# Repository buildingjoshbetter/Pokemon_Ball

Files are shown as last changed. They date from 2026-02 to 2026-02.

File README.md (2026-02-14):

<p align="center">
  PokeBall OpenClaw
</p>

<h1 align="center">PokeBall OpenClaw</h1>

<p align="center">
  <strong>Your AI agent, captured.</strong><br>
  A living PokeBall that thinks, glows, and talks back.
</p>

<p align="center">
  <a href="#installation">Install</a> · <a href="#what-it-does">What It Does</a> · <a href="#why">Why</a> · <a href="#demo">Demo</a>
</p>

---

## What It Does

PokeBall OpenClaw is a 3D-printed PokeBall with a Raspberry Pi 5 inside, running [OpenClaw](https://openclaw.ai) — the open-source AI agent. You talk to it through Telegram. It thinks using Claude, GPT, or whatever LLM you point it at. And while it works, the center button glows to tell you what's happening.

Blue means it's thinking. Green means it answered. Red means something broke. When nobody's talking to it, it breathes — a slow green pulse, like it's sleeping inside the ball, waiting.

It's not a toy. It's a fully functional AI assistant that happens to live inside the most iconic capture device in fiction.

### Features

- **LED state engine** — A stack-aware state machine drives three LEDs through the PokeBall's translucent button. Seven distinct states: boot, idle, thinking, tool call, success, error, disconnected. The transitions are instantaneous — you see the ball react the moment you hit send.
- **Heartbeat watchdog** — The OpenClaw plugin pings the LED daemon every 5 seconds. If the gateway crashes, the ball knows. Slow red pulse. No false positives, no polling logs, no fragile workarounds.
- **Fire-and-forget architecture** — The LED system never interferes with the agent. Every call from the plugin to the daemon is wrapped in try/catch. If the LEDs die, the agent keeps working. Nice-to-have, not a dependency.
- **Telegram-native** — Designed for Telegram via OpenClaw's built-in channel. Message the bot, watch the ball, get your answer. No app, no dashboard, no browser tab.
- **Fully reproducible** — Five STL files, three LEDs, three resistors, one Pi. Every file you need is in this repo. Print it, wire it, run one script, you're live.
- **Always on** — systemd service starts the LED daemon on boot. Power cycle the Pi and everything comes back automatically. Hackathon-grade reliability.

## Installation

### Prerequisites

- [OpenClaw](https://github.com/openclaw/openclaw) installed and configured
- Telegram bot set up in OpenClaw (create one via [@BotFather](https://t.me/BotFather))
- Raspberry Pi 5 (8GB recommended) or Pi 4 (4GB minimum)
- 3D-printed PokeBall shell ([STL files included](stl/))

### Quick Install

1. Clone this repo onto your Pi:
```bash
git clone https://github.com/buildingjoshbetter/Pokemon_Ball.git
cd Pokemon_Ball
```

2. Run the setup script:
```bash
chmod +x scripts/setup-pi.sh
./scripts/setup-pi.sh
```

3. Add your Telegram bot token to `~/.openclaw/openclaw.json`:
```json5
{
  channels: {
    telegram: {
      enabled: true,
      botToken: "YOUR_BOT_TOKEN_HERE"
    }
  },
  plugins: {
    "pokeball-led": {
      enabled: true
    }
  }
}
```

4. Restart OpenClaw:
```bash
openclaw gateway restart
```

5. Message your bot on Telegram. Watch the ball glow. That's it.

### Hardware Setup

Three LEDs, three resistors, one ground wire:

```
GPIO 17 (Pin 11) ──► 330Ω ──► Blue LED  ──► GND (Pin 9)
GPIO 27 (Pin 13) ──► 330Ω ──► Green LED ──► GND (Pin 9)
GPIO 22 (Pin 15) ──► 330Ω ──► Red LED   ──► GND (Pin 9)
```

Position all three behind the center button. The translucent plastic acts as a diffuser.

Full guides: [Wiring](hardware/wiring-guide.md) · [Assembly](hardware/assembly-guide.md) · [Parts List](hardware/parts-list.md) · [3D Printing](stl/README.md)

## Demo

Send a message. Watch the ball.

```
You: What's the weather in Austin today?

[PokeBall: 🟢 green pulse → 🔵 solid blue]

Agent: Currently 72°F and sunny in Austin, TX. High of 78°F expected
       this afternoon with clear skies through the evening.

[PokeBall: 🔵 blue → 🟢 green flash → 🟢 green pulse]
```

Ask something that requires tools — the ball blinks faster:

```
You: Search the web for the latest OpenClaw release notes

[PokeBall: 🟢 → 🔵 solid blue → 🔵 fast blink (tool call)]

Agent: OpenClaw 2026.2.12 was released today with patches for 40+
       security vulnerabilities. Key changes include...

[PokeBall: 🔵 fast blink → 🔵 solid → 🟢 flash → 🟢 pulse]
```

If something goes wrong, you know immediately:

```
You: Connect to my database and run the migration

[PokeBall: 🟢 → 🔵 solid → 🔴 fast blink]

Agent: Connection refused on port 5432. Is PostgreSQL running?

[PokeBall: 🔴 blink for 3s → 🟢 pulse]
```

Kill the OpenClaw gateway and the ball tells you:

```
$ openclaw gateway stop

[PokeBall: ... 15 seconds pass ... 🔴 slow pulse (breathing)]
[The ball knows. It's waiting for its trainer to come back.]

$ openclaw gateway start

[PokeBall: 🔴 slow pulse → 🟢 pulse]
[Back online. Ready.]
```

Run the full demo without Telegram:

```bash
bash scripts/demo-sequence.sh
```

## Why

I was sitting at a hackathon staring at a terminal. Everyone around me had the same thing — a laptop, a code editor, an agent running in a window somewhere. You couldn't tell who was running what. You couldn't tell if anything was happening. The AI was invisible.

And I thought: that's the problem with agents. Not just at hackathons — everywhere. You fire off a request and then you sit there. Is it thinking? Did it crash? Is it stuck in a loop? You check the terminal. You check the logs. You wait. The most powerful technology we've ever built, and it has the presence of a loading spinner.

I had a 3D printer. I had a Raspberry Pi. I had a PokeBall model I'd been meaning to print for two years. And I had OpenClaw, an open-source agent that runs on a Pi and talks through Telegram.

So I caught one.

Three LEDs behind the button. A Python daemon listening on localhost. An OpenClaw plugin that fires on every lifecycle event. When the agent thinks, the ball glows blue. When it finishes, green flash. When it fails, red. When nobody's talking to it, it breathes — slow green pulse, like something alive is sleeping inside.

The moment I put it on the table, people walked over. Not because the code was impressive — it's straightforward. They walked over because they could *see* the AI. For the first time, the invisible thing had a body. It sat on the desk and it glowed and it breathed and when you talked to it, it reacted. That changes how you think about it. That changes how everyone around you thinks about it.

$105 in parts. An afternoon of work. Every file you need is in this repo.

Your move.

## Built By

**[@Building_Josh](https://x.com/Building_Josh)**

Built at a hackathon because AI agents deserve a body, and every trainer deserves a PokeBall on their desk.

## License

[MIT](LICENSE) — Gotta catch 'em all. Or at least this one.

---

<p align="center">
  <em>"I caught an AI."</em>
</p>

<p align="center">
  PokeBall OpenClaw
</p>

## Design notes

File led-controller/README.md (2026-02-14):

# LED Controller

Python daemon that drives the PokeBall's LEDs based on state commands from the OpenClaw plugin.

## How It Works

The LED controller is a FastAPI server running on `127.0.0.1:8420`. It receives HTTP requests from the OpenClaw plugin and translates them into GPIO signals that control three LEDs (red, green, blue).

### API Endpoints

| Method | Endpoint | Description |
|---|---|---|
| `PUT` | `/state` | Set LED state (`{"state": "idle"}`) |
| `POST` | `/heartbeat` | Heartbeat from OpenClaw plugin |
| `GET` | `/status` | Get current LED state |

### State Machine

The controller uses a stack-aware state machine:

```
BOOT ──────► IDLE ◄──── SUCCESS
               │            ▲
               ▼            │
         AGENT_ACTIVE ──────┘
               │
               ▼
           TOOL_CALL ───► AGENT_ACTIVE (pop stack)

  Any state ──► ERROR
  Any state ──► DISCONNECTED (heartbeat timeout)
```

## Installation

### On the Raspberry Pi

```bash
chmod +x install.sh
./install.sh
```

This installs the daemon to `/opt/pokeball-openclaw/led-controller/`, creates a Python virtual environment, and sets up a systemd service that starts on boot.

### Manual Test

```bash
# Test LED wiring
python3 test_leds.py

# Test the daemon
uvicorn led_daemon:app --host 127.0.0.1 --port 8420

# In another terminal:
curl -X PUT http://127.0.0.1:8420/state \
  -H "Content-Type: application/json" \
  -d '{"state": "agent_active"}'
```

## Files

| File | Description |
|---|---|
| `led_daemon.py` | FastAPI server + heartbeat watchdog |
| `led_states.py` | State machine with stack-aware transitions |
| `led_hardware.py` | gpiozero GPIO abstraction |
| `test_leds.py` | Quick wiring verification script |
| `pokeball-leds.service` | systemd unit file |
| `install.sh` | Automated installer |

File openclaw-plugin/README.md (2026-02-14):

# OpenClaw PokeBall LED Plugin

OpenClaw plugin that bridges agent lifecycle events to the PokeBall's LED indicators.

## How It Works

This plugin hooks into four OpenClaw lifecycle events:

| Event | LED State | Visual |
|---|---|---|
| `before_agent_start` | Agent Active | Solid blue |
| `before_tool_call` | Tool Call | Fast blue blink |
| `after_tool_call` | Agent Active | Back to solid blue |
| `agent_end` (success) | Success | Green flash |
| `agent_end` (error) | Error | Red blink |

It also runs a background heartbeat service that pings the LED daemon every 5 seconds. If the daemon stops receiving heartbeats (gateway crash), it transitions LEDs to a disconnected state (slow red pulse).

## Installation

### 1. Build the plugin

```bash
cd openclaw-plugin
npm install
npm run build
```

### 2. Copy to OpenClaw plugins directory

```bash
cp -r dist/ ~/.openclaw/plugins/pokeball-led/
cp package.json ~/.openclaw/plugins/pokeball-led/
```

### 3. Enable in OpenClaw config

Add to `~/.openclaw/openclaw.json`:

```json5
{
  plugins: {
    "pokeball-led": {
      enabled: true
    }
  }
}
```

### 4. Restart OpenClaw gateway

```bash
openclaw gateway restart
```

## Configuration

Set the `POKEBALL_LED_URL` environment variable to override the default LED daemon URL:

```bash
export POKEBALL_LED_URL="http://127.0.0.1:8420"
```

## Files

| File | Description |
|---|---|
| `src/index.ts` | Plugin entry: registers hooks + heartbeat service |
| `src/led-client.ts` | HTTP client for the LED daemon |
| `src/hooks/agent-lifecycle/` | Agent start/end hook |
| `src/hooks/tool-lifecycle/` | Tool call start/end hook |

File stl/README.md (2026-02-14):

# 3D Printing Guide

Five parts make up the PokeBall enclosure. Print them separately with the colors and settings below.

## Parts Overview

| Part | File | Color | Description |
|---|---|---|---|
| Top Half | `top-half.stl` | **Red** | Upper shell of the PokeBall |
| Bottom Half | `bottom-half.stl` | **White** | Lower shell of the PokeBall |
| Center Band | `center-band.stl` | **Black** | Equator band that joins the two halves |
| Button | `button.stl` | **White or translucent** | Center button (LED shines through this) |
| Button Bezel | `button-bezel.stl` | **Dark gray or black** | Ring around the center button |

## Print Settings

| Setting | Value | Notes |
|---|---|---|
| Layer Height | 0.2mm | Standard quality, good enough for the shell |
| Infill | 15% | 20% for center band (structural) |
| Supports | Yes | For top-half and bottom-half interior cavities |
| Walls | 3 perimeters | Strength without excess weight |
| Material | PLA | PETG also works, PLA is easiest |
| Nozzle | 0.4mm | Standard |

## Special Notes

- **Button**: If you can print in translucent/clear PLA, do it. The LED behind it will glow through beautifully. If not, white PLA works fine - the light still diffuses through at 100% infill.
- **Top Half**: The interior needs supports. Orient it with the dome facing up.
- **Bottom Half**: Orient dome facing down. You may want to drill a small hole in the back for USB-C power cable access.
- **Center Band**: No supports needed. This is the structural piece - use 20% infill.
- **Button Bezel**: Small part, prints fast. Press-fits around the button.

## Assembly Order

1. Print all five parts
2. Drill a hole in the bottom half for USB-C power cable
3. Optionally drill/enlarge the button hole if needed for LED fitment
4. Press-fit the button into the button bezel
5. Insert the button+bezel assembly into the center band
6. Snap/glue the top half onto the center band
7. Snap/glue the bottom half onto the center band
8. The Pi and LEDs go inside before closing (see [hardware/assembly-guide.md](../hardware/assembly-guide.md))

## Estimated Print Times

| Part | Time | Filament |
|---|---|---|
| Top Half | ~3 hours | ~30g |
| Bottom Half | ~3 hours | ~35g |
| Center Band | ~1.5 hours | ~15g |
| Button | ~15 min | ~2g |
| Button Bezel | ~20 min | ~3g |
| **Total** | **~8 hours** | **~85g** |

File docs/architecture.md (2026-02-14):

# Architecture

Technical deep-dive into how the PokeBall OpenClaw rig works.

## System Overview

```
┌─────────────┐         ┌──────────────────────────────────────┐
│  Your Phone  │         │         RASPBERRY PI 5 (PokeBall)    │
│  (Telegram)  │◄───────►│                                      │
└─────────────┘         │  ┌──────────────────────────────┐    │
                        │  │     OpenClaw Gateway          │    │
                        │  │     (Node.js)                 │    │
                        │  │                               │    │
                        │  │  ┌─────────────────────────┐  │    │
                        │  │  │  pokeball-led plugin     │  │    │
                        │  │  │                          │  │    │
                        │  │  │  Hooks:                  │  │    │
                        │  │  │   before_agent_start     │──┼──┐ │
                        │  │  │   agent_end              │  │  │ │
                        │  │  │   before_tool_call       │  │  │ │
                        │  │  │   after_tool_call        │  │  │ │
                        │  │  │                          │  │  │ │
                        │  │  │  Service:                │  │  │ │
                        │  │  │   heartbeat (5s)         │──┼──┤ │
                        │  │  └─────────────────────────┘  │  │ │
                        │  └──────────────────────────────┘  │ │
                        │                                     │ │
                        │  HTTP POST to 127.0.0.1:8420       │ │
                        │                                     │ │
                        │  ┌──────────────────────────────┐  │ │
                        │  │   LED Controller Daemon       │◄─┘ │
                        │  │   (Python / FastAPI)          │    │
                        │  │                               │    │
                        │  │   State Machine (stack-aware)  │    │
                        │  │          │                    │    │
                        │  │          ▼                    │    │
                        │  │   gpiozero GPIO control       │    │
                        │  │     │       │       │         │    │
                        │  └─────┼───────┼───────┼─────────┘    │
                        │        │       │       │              │
                        │     [RED]   [GREEN]  [BLUE]           │
                        │     GPIO22  GPIO27   GPIO17           │
                        └──────────────────────────────────────┘
```

## Communication Flow

1. **User sends Telegram message** to the bot
2. **OpenClaw Gateway** receives the message via Telegram channel
3. **`before_agent_start` hook fires** → plugin POSTs `{"state": "agent_active"}` to LED daemon
4. **LED daemon** transitions state machine → blue LED turns on solid
5. **Agent calls a tool** → `before_tool_call` hook → blue LED starts blinking fast
6. **Tool returns** → `after_tool_call` hook → blue LED back to solid
7. **Agent finishes** → `agent_end` hook → green LED flashes (success) or red blinks (error)
8. **Auto-transition** → back to green pulse (idle)

## State Machine

```
                    ┌─────────┐
             ┌──────│  BOOT   │
             │      └────┬────┘
             │           │ heartbeat received
             │      ┌────▼────┐
             │  ┌──►│  IDLE   │◄──────────────┐
             │  │   └────┬────┘               │
             │  │        │ before_agent_start  │ auto (500ms)
             │  │   ┌────▼─────────┐    ┌─────┴─────┐
             │  │   │ AGENT_ACTIVE │───►│  SUCCESS   │
             │  │   └────┬────┬────┘    └───────────┘
             │  │        │    │
             │  │        │    │ agent_end (error)
             │  │        │    │         ┌───────┐
             │  │        │    └────────►│ ERROR │
             │  │        │              └───────┘
             │  │        │ before_tool_call
             │  │   ┌────▼────┐
             │  │   │TOOL_CALL│──► after_tool_call ──► AGENT_ACTIVE
             │  │   └─────────┘                        (pop stack)
             │  │
             │  │  heartbeat timeout (15s)
             │  │   ┌──────────────┐
             │  └───│ DISCONNECTED │
             │      └──────────────┘
             │           │ heartbeat resumed
             └───────────┘
```

### Stack-Aware Transitions

The state machine uses a stack (not a simple variable) to handle nested events:

- `TOOL_CALL` **pushes** onto the stack
- `after_tool_call` **pops** back to `AGENT_ACTIVE`
- Terminal states (`IDLE`, `SUCCESS`, `ERROR`) **collapse** the entire stack

This prevents a bug where ending a tool call would jump straight to `IDLE` instead of returning to `AGENT_ACTIVE`.

## Heartbeat Watchdog

The plugin sends a heartbeat POST every 5 seconds. The LED daemon runs a watchdog thread that checks:

- If no heartbeat received for 15 seconds → transition to `DISCONNECTED`
- When heartbeat resumes → transition back to `IDLE`

This handles gateway crashes, network issues, or the OpenClaw process being stopped.

## Error Handling

The plugin uses **fire-and-forget** semantics:
- Every HTTP call to the LED daemon is wrapped in try/catch
- Failures are logged as warnings, never thrown
- The agent continues working normally even if LEDs are unreachable
- The LED daemon is a **nice-to-have**, not a dependency

## Port and Security

- LED daemon binds to `127.0.0.1:8420` (localhost only)
- Not exposed to the network
- No authentication needed (only local processes can reach it)

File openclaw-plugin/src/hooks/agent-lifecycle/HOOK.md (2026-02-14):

---
name: pokeball-agent-lifecycle
description: Sends LED state updates when agent starts/ends processing
events:
  - before_agent_start
  - agent_end
enabled: true
---

# PokeBall Agent Lifecycle Hook

Updates the PokeBall LEDs when the OpenClaw agent begins or finishes
processing a user message.

- `before_agent_start` -> Blue LED (thinking)
- `agent_end` (success) -> Green flash
- `agent_end` (error) -> Red blink

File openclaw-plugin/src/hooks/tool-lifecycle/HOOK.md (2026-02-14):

---
name: pokeball-tool-lifecycle
description: Sends LED state updates when tools are called during agent processing
events:
  - before_tool_call
  - after_tool_call
enabled: true
---

# PokeBall Tool Lifecycle Hook

Updates the PokeBall LEDs during tool execution:

- `before_tool_call` -> Fast blue blink (working)
- `after_tool_call` -> Back to solid blue (agent still thinking)

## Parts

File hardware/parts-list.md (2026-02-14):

# Parts List

Everything you need to build the PokeBall OpenClaw rig.

## Electronics

| Part | Qty | Price | Notes |
|---|-----|---|---|
| Raspberry Pi 5 (8GB) | 1 | ~$80 | Pi 4 (4GB+) also works |
| USB-C power supply (5V 5A) | 1 | ~$12 | Use the official Pi power supply |
| MicroSD card (32GB+, A2 rated) | 1 | ~$10 | Or boot from USB SSD |
| 5mm LED - Red | 1 | ~$0.10 | Standard through-hole |
| 5mm LED - Green | 1 | ~$0.10 | Standard through-hole |
| 5mm LED - Blue | 1 | ~$0.10 | Standard through-hole |
| 330Ω resistor | 3 | ~$0.10 | 220Ω-470Ω all work |
| Jumper wires (F-F) | 4 | ~$0.50 | Female-to-female for GPIO header |
| Small heatsink | 1 | ~$3 | Optional but recommended |

## 3D Printing

| Part | Material | Notes |
|---|---|---|
| PLA filament - Red | ~30g | Top half |
| PLA filament - White | ~37g | Bottom half + button |
| PLA filament - Black | ~18g | Center band + button bezel |

## Tools

- Soldering iron (or breadboard for prototyping)
- Hot glue gun (for mounting Pi inside shell)
- Drill with small bit (for USB-C cable hole)
- Wire strippers

## Total Cost

| Category | Cost |
|---|---|
| Raspberry Pi 5 + power + SD | ~$102 |
| LEDs + resistors + wires | ~$1 |
| 3D print filament | ~$2 |
| **Total** | **~$105** |

If you already have a Pi, total additional cost is under $5.

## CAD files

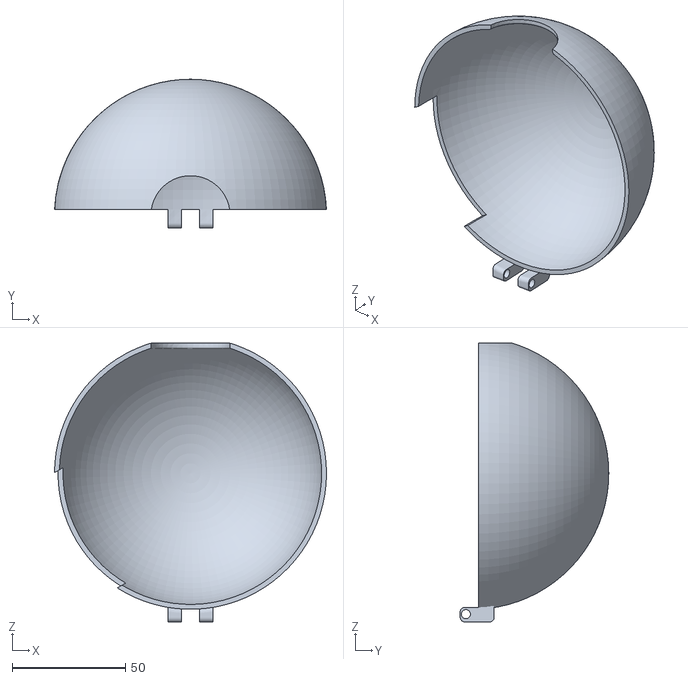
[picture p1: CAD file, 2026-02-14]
stl/top-half.stl
119.9 x 65.5 x 122.9

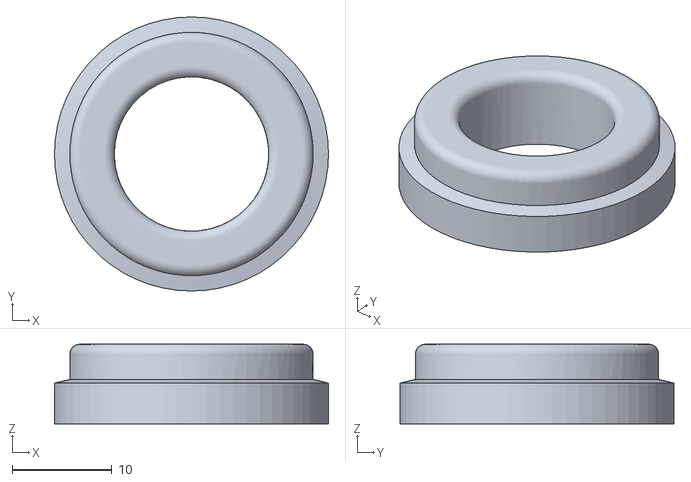
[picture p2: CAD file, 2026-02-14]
stl/button-bezel.stl
27.5 x 27.5 x 8.00

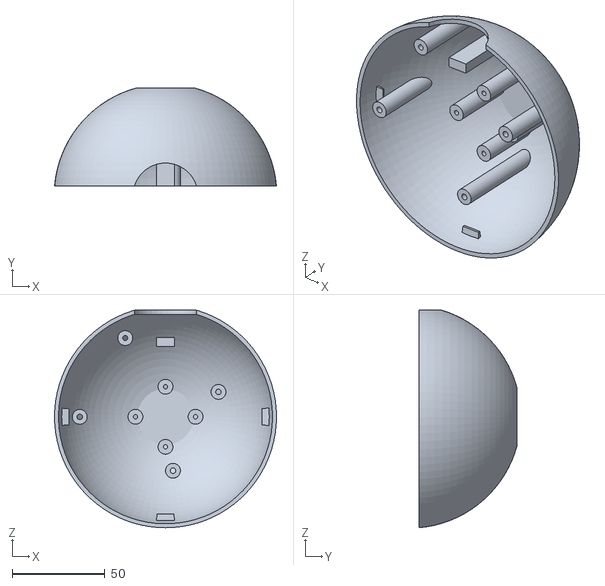
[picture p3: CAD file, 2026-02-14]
stl/bottom-half.stl
119.6 x 53.0 x 117.2

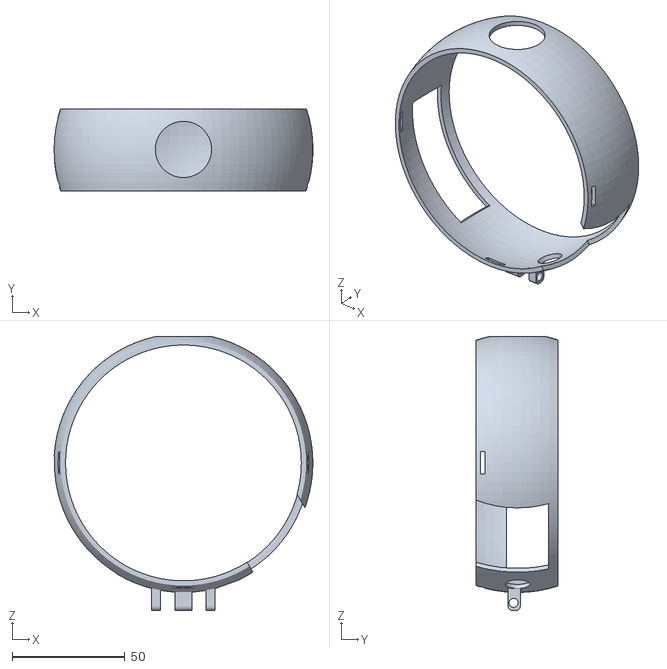
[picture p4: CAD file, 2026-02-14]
stl/center-band.stl
114.9 x 36.5 x 121.6

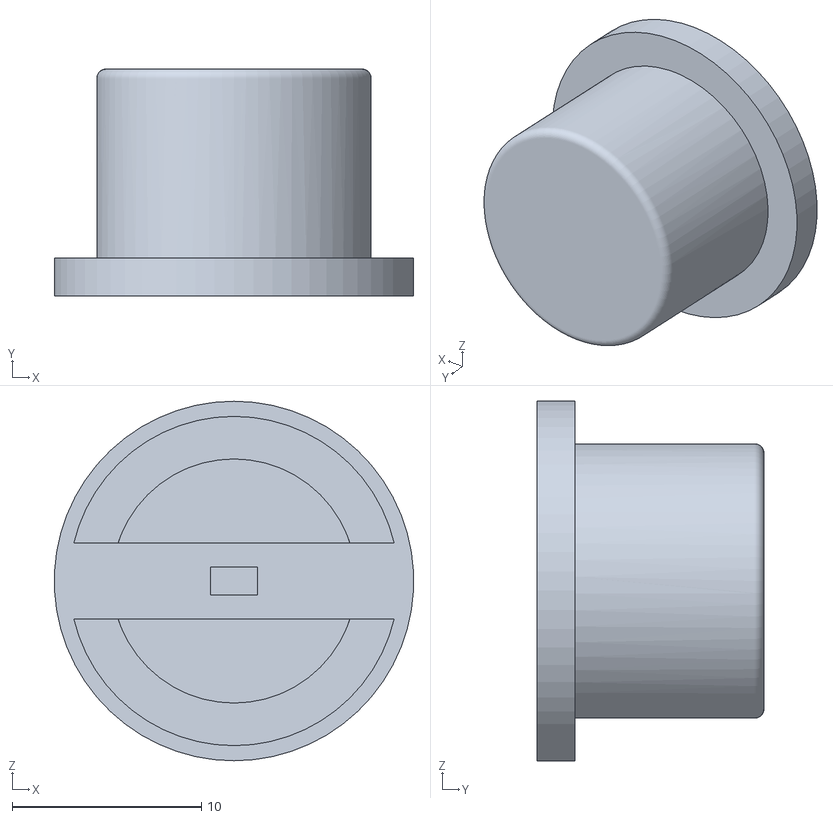
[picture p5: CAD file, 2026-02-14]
stl/button.stl
19.0 x 12.0 x 19.0

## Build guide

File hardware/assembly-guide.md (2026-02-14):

# Assembly Guide

How to put together the PokeBall OpenClaw rig. Total time: ~30 minutes (after printing).

## Before You Start

Make sure you have:
- All 5 printed parts (see [stl/README.md](../stl/README.md))
- Raspberry Pi 5 with OS installed and OpenClaw configured
- 3 LEDs wired to the Pi (see [wiring-guide.md](./wiring-guide.md))
- USB-C power cable
- Hot glue gun
- Small drill

## Assembly Steps

### 1. Prep the Bottom Half

Drill a hole in the back of the **bottom-half** piece for the USB-C power cable. Size it just large enough for the cable to pass through snugly.

Optionally drill a small hole nearby for HDMI if you want video output during demos.

### 2. Mount the Raspberry Pi

Place the Pi inside the bottom half. Use hot glue on the corners to secure it. Make sure:
- The USB-C power port aligns with the hole you drilled
- The GPIO pins face upward (toward where the button will be)
- There's room for the heatsink on top of the CPU

### 3. Attach the Heatsink

Stick the heatsink onto the Pi's CPU before closing. The PokeBall is semi-enclosed, so passive cooling helps.

### 4. Position the LEDs

Cluster the three LEDs together, pointing upward toward the center button hole. Hot glue them in place. The wires should be long enough to reach the GPIO pins with a little slack.

### 5. Assemble the Button

Press-fit the **button** piece into the **button-bezel** piece. This assembly sits in the center hole of the **center-band**.

### 6. Close It Up

1. Place the **center-band** onto the **bottom-half** (snap or glue)
2. Insert the **button+bezel** into the center-band's button hole
3. Route the USB-C cable out through the back hole
4. Place the **top-half** onto the center-band (snap or glue)

### 7. Final Check

- USB-C cable accessible from outside
- LEDs visible through the center button
- Pi powered on and accessible via SSH
- Run `python3 test_leds.py` to verify everything works

## Tips

- **Don't permanently glue the top half** until everything is tested. Use friction fit or small dabs of hot glue that can be broken if needed.
- **Cable management**: Coil excess LED wires inside. Use small cable ties if needed.
- **Ventilation**: The PokeBall doesn't need to be airtight. Small gaps between parts provide enough airflow for the Pi 5 with a heatsink.
- **Demo setup**: During your presentation, you can open the top half to show the internals. This is a great "reveal" moment.

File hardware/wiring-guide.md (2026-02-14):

# Wiring Guide

Three LEDs connect to the Raspberry Pi's GPIO header. That's it - 4 wires total.

## GPIO Pin Mapping

| LED | GPIO Pin | Physical Pin | Resistor |
|-----|---|---|---|
| Blue | GPIO 17 | Pin 11 | 330Ω |
| Green | GPIO 27 | Pin 13 | 330Ω |
| Red | GPIO 22 | Pin 15 | 330Ω |
| Ground (shared) | GND | Pin 9 | - |

## Wiring Diagram

```
Raspberry Pi GPIO Header (pins 1-20 shown)
┌─────────────────────────────┐
│  (3.3V) 1  ●  ● 2  (5V)    │
│  (SDA)  3  ●  ● 4  (5V)    │
│  (SCL)  5  ●  ● 6  (GND)   │
│         7  ●  ● 8          │
│  (GND)  9  ●──● 10         │
│ (GP17) 11  ●  ● 12         │  ← GPIO 17 = Blue LED
│ (GP27) 13  ●  ● 14  (GND)  │  ← GPIO 27 = Green LED
│ (GP22) 15  ●  ● 16         │  ← GPIO 22 = Red LED
│  (3.3V)17  ●  ● 18         │
│        19  ●  ● 20  (GND)  │
└─────────────────────────────┘

Wiring for each LED:

  GPIO Pin ──→ 330Ω Resistor ──→ LED (+ long leg) ──→ LED (- short leg) ──→ GND

All three LEDs share one GND connection (Pin 9).
```

## Step-by-Step

1. **Connect the ground wire.** Run a jumper wire from **Pin 9 (GND)** to a common ground point (breadboard ground rail, or solder all LED ground legs together).

2. **Wire the Blue LED.**
   - GPIO 17 (Pin 11) → 330Ω resistor → Blue LED anode (+, long leg)
   - Blue LED cathode (-, short leg) → GND

3. **Wire the Green LED.**
   - GPIO 27 (Pin 13) → 330Ω resistor → Green LED anode (+, long leg)
   - Green LED cathode (-, short leg) → GND

4. **Wire the Red LED.**
   - GPIO 22 (Pin 15) → 330Ω resistor → Red LED anode (+, long leg)
   - Red LED cathode (-, short leg) → GND

## LED Placement

Position all three LEDs behind the PokeBall's center button. The translucent/white button acts as a diffuser, blending the colors:

```
        ┌──────────────┐
        │   PokeBall   │
        │   Button     │
        │  (diffuser)  │
        ├──────────────┤
        │  🔴 🟢 🔵   │  ← LEDs pointing at button
        │  (R) (G) (B) │
        │              │
        │  [  Pi 5  ]  │
        └──────────────┘
```

Hot glue the LEDs in place pointing toward the button. Leave enough wire length to open the PokeBall if needed.

## Verification

After wiring, run the test script:

```bash
cd /opt/pokeball-openclaw/led-controller
python3 test_leds.py
```

This cycles through each LED individually, then demos all states.

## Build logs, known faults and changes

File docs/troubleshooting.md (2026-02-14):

# Troubleshooting

Common issues and fixes for the PokeBall OpenClaw rig.

## LEDs don't light up at all

**Check wiring polarity.** LEDs only work in one direction. The longer leg is positive (anode) and goes toward the GPIO pin (through the resistor). The shorter leg is negative (cathode) and goes to ground.

**Check GPIO pins.** Run `python3 test_leds.py` to test each LED individually. If no LEDs work, check that your ground wire is connected to Pin 9.

**Check the daemon is running:**
```bash
sudo systemctl status pokeball-leds
curl http://127.0.0.1:8420/status
```

## LEDs stay in BOOT (cycling R/G/B forever)

The LED daemon is running but hasn't received a heartbeat from OpenClaw. This means OpenClaw's gateway isn't running or the plugin isn't loaded.

**Fix:**
```bash
# Check OpenClaw is running
openclaw gateway status

# Check plugin is enabled
cat ~/.openclaw/openclaw.json | grep pokeball

# Restart gateway
openclaw gateway restart
```

## LEDs show DISCONNECTED (slow red pulse)

The LED daemon lost contact with the OpenClaw gateway (no heartbeat for 15+ seconds).

**Fix:**
```bash
# Check OpenClaw gateway
openclaw gateway status

# Check logs
journalctl -u pokeball-leds -f
```

## Telegram bot doesn't respond

**Check bot token:**
```bash
# Verify token is set in config
cat ~/.openclaw/openclaw.json | grep botToken
```

**Check pairing:**
```bash
# List paired users
openclaw channels status
```

**Common fix:** Make sure you messaged the bot first on Telegram to trigger the pairing flow, then approved the pairing code.

## LED daemon crashes on startup

**"Permission denied" for GPIO:**
```bash
# Add user to gpio group
sudo usermod -a -G gpio $USER
# Log out and back in, or reboot
```

**"Address already in use":**
```bash
# Something else is on port 8420
sudo lsof -i :8420
# Kill it or change the port in led_daemon.py
```

## Pi overheating inside the PokeBall

- Make sure the heatsink is attached to the CPU
- Don't seal the PokeBall airtight - small gaps provide airflow
- For heavy usage, leave the top half slightly open
- Check temperature: `vcgencmd measure_temp`

## Plugin hooks not firing

Check that the hooks are registered correctly:
```bash
openclaw hooks list
```

Make sure the plugin directory structure is correct:
```
~/.openclaw/plugins/pokeball-led/
├── dist/
│   ├── index.js
│   ├── led-client.js
│   └── hooks/
│       ├── agent-lifecycle/
│       │   └── handler.js
│       └── tool-lifecycle/
│           └── handler.js
└── package.json
```

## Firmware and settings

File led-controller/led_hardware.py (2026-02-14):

"""
PokeBall LED Hardware Abstraction

Wraps gpiozero for GPIO control. On non-Pi hardware (dev/testing),
gpiozero automatically falls back to a mock pin factory.
"""

import threading
import time
from typing import Optional

try:
    from gpiozero import LED, PWMLED
    GPIO_AVAILABLE = True
except ImportError:
    GPIO_AVAILABLE = False


class LedController:
    """Controls three LEDs (red, green, blue) on GPIO pins."""

    def __init__(self, red_pin: int = 22, green_pin: int = 27, blue_pin: int = 17):
        self._animation_stop = threading.Event()
        self._animation_thread: Optional[threading.Thread] = None

        if GPIO_AVAILABLE:
            # PWMLED supports brightness control for pulse/fade effects
            self.red = PWMLED(red_pin)
            self.green = PWMLED(green_pin)
            self.blue = PWMLED(blue_pin)
            self._leds = {"red": self.red, "green": self.green, "blue": self.blue}
        else:
            self.red = None
            self.green = None
            self.blue = None
            self._leds = {}
            print("[LED] GPIO not available - running in mock mode")

    def all_off(self):
        """Turn all LEDs off and stop any animation."""
        self._stop_animation()
        for led in self._leds.values():
            if led:
                led.off()

    def apply_pattern(self, pattern: dict):
        """Apply an LED pattern from LED_PATTERNS."""
        self._stop_animation()

        ptype = pattern["type"]

        if ptype == "solid":
            self._solid(pattern["color"])
        elif ptype == "blink":
            self._start_animation(self._blink, pattern["color"], pattern["interval"])
        elif ptype == "pulse":
            self._start_animation(self._pulse, pattern["color"], pattern["interval"])
        elif ptype == "cycle":
            self._start_animation(self._cycle, pattern["colors"], pattern["interval"])
        elif ptype == "flash":
            self._start_animation(
                self._flash, pattern["color"], pattern["duration"], pattern.get("then")
            )

    def _solid(self, color: str):
        """Turn on a single LED at full brightness."""
        self.all_off()
        led = self._leds.get(color)
        if led:
            led.value = 1.0

    def _blink(self, color: str, interval: float):
        """Blink a single LED on/off."""
        led = self._leds.get(color)
        if not led:
            return
        while not self._animation_stop.is_set():
            led.value = 1.0
            if self._animation_stop.wait(interval):
                break
            led.value = 0.0
            if self._animation_stop.wait(interval):
                break

    def _pulse(self, color: str, interval: float):
        """Smooth fade in/out (breathing effect)."""
        led = self._leds.get(color)
        if not led:
            return
        steps = 50
        step_time = interval / steps
        while not self._animation_stop.is_set():
            # Fade in
            for i in range(steps):
                if self._animation_stop.is_set():
                    return
                led.value = i / steps
                time.sleep(step_time)
            # Fade out
            for i in range(steps, 0, -1):
                if self._animation_stop.is_set():
                    return
                led.value = i / steps
                time.sleep(step_time)

    def _cycle(self, colors: list[str], interval: float):
        """Cycle through colors one at a time."""
        while not self._animation_stop.is_set():
            for color in colors:
                if self._animation_stop.is_set():
                    return
                for led in self._leds.values():
                    if led:
                        led.off()
                led = self._leds.get(color)
                if led:
                    led.value = 1.0
                if self._animation_stop.wait(interval):
                    return

    def _flash(self, color: str, duration: float, then_state=None):
        """Brief flash, then return to callback state."""
        led = self._leds.get(color)
        if led:
            led.value = 1.0
        self._animation_stop.wait(duration)
        if led:
            led.off()
        # The "then" transition is handled by the state machine via auto-transition

    def _start_animation(self, func, *args):
        """Start an animation in a background thread."""
        self._animation_stop.clear()
        self._animation_thread = threading.Thread(
            target=func, args=args, daemon=True
        )
        self._animation_thread.start()

    def _stop_animation(self):
        """Stop any running animation."""
        self._animation_stop.set()
        if self._animation_thread and self._animation_thread.is_alive():
            self._animation_thread.join(timeout=1.0)
        self._animation_thread = None
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

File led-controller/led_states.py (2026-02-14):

"""
PokeBall LED State Machine

Stack-aware state machine that manages LED transitions based on
OpenClaw agent lifecycle events. The stack ensures nested events
(like tool calls inside an agent run) resolve correctly.
"""

from enum import Enum
from typing import Callable, Optional
import threading


class LedState(Enum):
    BOOT = "boot"
    IDLE = "idle"
    AGENT_ACTIVE = "agent_active"
    TOOL_CALL = "tool_call"
    SUCCESS = "success"
    ERROR = "error"
    DISCONNECTED = "disconnected"


# LED patterns: keyed by state
# "type" determines behavior:
#   solid   - constant on
#   blink   - on/off at interval
#   pulse   - smooth fade in/out at interval
#   cycle   - rotate through colors at interval
#   flash   - brief on, then auto-transition to "then" state
LED_PATTERNS = {
    LedState.BOOT: {
        "type": "cycle",
        "colors": ["red", "green", "blue"],
        "interval": 0.5,
    },
    LedState.IDLE: {
        "type": "pulse",
        "color": "green",
        "interval": 2.0,
    },
    LedState.AGENT_ACTIVE: {
        "type": "solid",
        "color": "blue",
    },
    LedState.TOOL_CALL: {
        "type": "blink",
        "color": "blue",
        "interval": 0.1,
    },
    LedState.SUCCESS: {
        "type": "flash",
        "color": "green",
        "duration": 0.5,
        "then": LedState.IDLE,
    },
    LedState.ERROR: {
        "type": "blink",
        "color": "red",
        "interval": 0.2,
    },
    LedState.DISCONNECTED: {
        "type": "pulse",
        "color": "red",
        "interval": 2.0,
    },
}


class StateMachine:
    """Stack-aware LED state machine.

    The stack handles nested events correctly:
    - TOOL_CALL pushes onto the stack
    - Ending a tool call pops back to AGENT_ACTIVE
    - Terminal states (IDLE, SUCCESS, ERROR) collapse the stack
    """

    def __init__(self, on_state_change: Callable[[LedState], None]):
        self._stack: list[LedState] = [LedState.BOOT]
        self._on_change = on_state_change
        self._lock = threading.Lock()

    @property
    def current(self) -> LedState:
        with self._lock:
            return self._stack[-1]

    def transition(self, new_state: LedState) -> LedState:
        with self._lock:
            old = self._stack[-1]

            if new_state == LedState.TOOL_CALL:
                # Push: tool call inside an agent run
                self._stack.append(new_state)
            elif new_state == LedState.AGENT_ACTIVE and old == LedState.TOOL_CALL:
                # Pop: tool call finished, return to agent active
                self._stack.pop()
            elif new_state in (
                LedState.IDLE,
                LedState.SUCCESS,
                LedState.ERROR,
                LedState.DISCONNECTED,
                LedState.BOOT,
            ):
                # Collapse: terminal states reset the stack
                self._stack = [new_state]
            else:
                # Replace top of stack
                self._stack[-1] = new_state

            current = self._stack[-1]

        # Notify outside the lock to avoid deadlocks
        self._on_change(current)
        return current

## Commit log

2026-02-14 Initial release: PokeBall OpenClaw rig
    3D-printed PokeBall housing a Raspberry Pi 5 running OpenClaw with
    LED indicators driven by agent lifecycle events via Telegram.
    - 5 STL files for 3D printing (renamed from Spanish originals)
    - Python LED controller daemon with stack-aware state machine
    - OpenClaw TypeScript plugin with lifecycle hooks + heartbeat
    - Full hardware docs: wiring, parts list, assembly guide
    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
    [bottom-half.stl, button-bezel.stl, button.stl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]
2026-02-14 Restructure README to match Wave/Banana Man format
    - Move logo to assets/ folder
    - Add centered nav links (Install · What It Does · Why · Demo)
    - Add personal narrative "Why" section
    - Add conversation-style demo with LED state indicators
    - Match bold+dash feature bullet style
    - Add centered closing quote
